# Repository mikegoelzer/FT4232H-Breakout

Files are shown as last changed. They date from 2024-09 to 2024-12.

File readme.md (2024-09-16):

# FT4232H Breakout Board

Breakout board for the FT4232H to support SPI flash programming and JTAG, as well as two UARTs.

<p align="center">
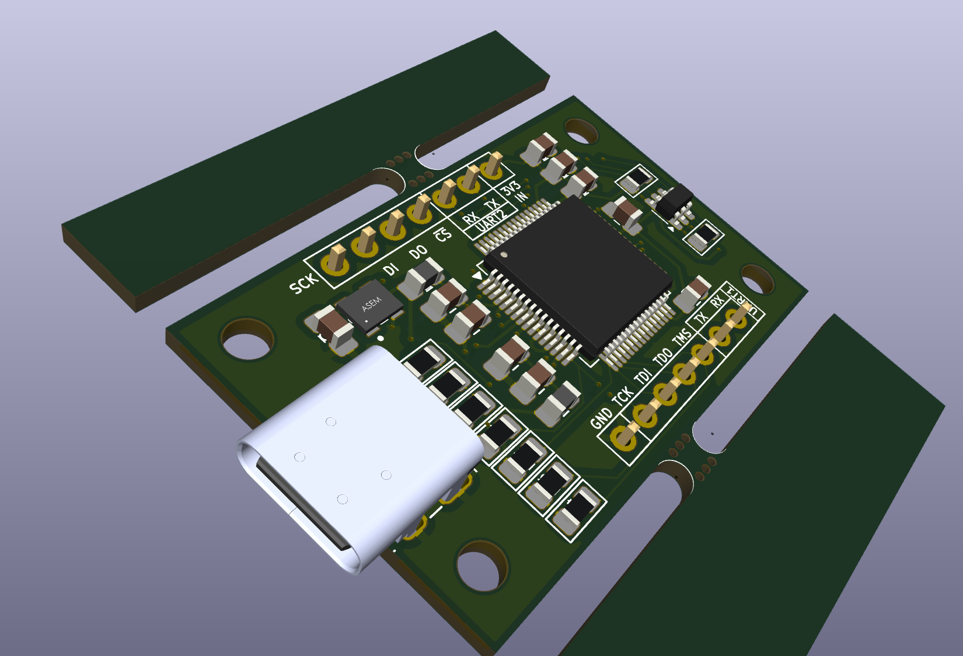
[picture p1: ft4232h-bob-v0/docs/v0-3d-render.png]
FT4232H Breakout Board 3D Render
  
</p>

# Contents

 - [`ft4232h-bob-v0/`](ft4232h-bob-v0/) - Rev 0 of hardware
 - [`mfgr/`](mfgr/) - Files used to initial the EEPROM in a newly built device. See [`mfgr/README.md`](mfgr/README.md)
 - [`ft4232h-bob-v0/docs/`](ft4232h-bob-v0/docs/) - Documentation:
   - [`ft4232h-bob-v0/docs/Improvements.md`](ft4232h-bob-v0/docs/Improvements.md) - Improvements to make to for next revision of board

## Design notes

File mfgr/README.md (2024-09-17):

# FTDI FT4232H Breakout Board EEPROM Programmer

Requires:  [`ftdi-eeprom`](https://github.com/nblock/libftdi/tree/master/ftdi_eeprom) utility in PATH

```
sudo apt install ftdi-eeprom
```

The EEPROM is flashed from `config.txt` file in this directory. Run `man ftdi_eeprom` to see possible config file options.

### Reading

Read the current EEPROM settings:

```
make read
```

### Flashing

Flashing from `config.txt` file's settings:

```
make flash
```

**Notes**

 - You must UNPLUG and REPLUG the FTDI device for `make flash` changes to become visible to the OS.
 - It is not necessary to first erase the EEPROM.
 - When the EEPROM is first initialized on a new board, `make flash` may need to be run **twice** for unknown reasons.

### Erasing

To erase the EEPROM (not in Makefile because not normally required):

```
sudo ftdi_eeprom --device i:0x0403:0x6011 --verbose --erase-eeprom config.txt
```

You will now need to run `make flash` **twice** to write the new settings. The first `make flash` never "takes" for some reason.

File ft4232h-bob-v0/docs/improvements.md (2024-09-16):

# Improvements for FT4232H Breakout Board v1

This is a list of improvements to implement when transitioning from v0 to v1 of the board.

- [ ] `MISO` and `MOSI` are reversed, as are the `DI`/`DO` silkscreens:
  - [ ] Schematic net names: swap MISO and MOSI on pins 27 and 28 so they are like this:
    - [ ] Pin 27:  MOSI
    - [ ] Pin 28:  MISO
    - [ ] Breakout pin 6:  MOSI
    - [ ] Breakout pin 5:  MISO
  - [ ] On PCB, now swap silkscreen DI/DO so they match:
    - [ ] MOSI = DO
    - [ ] MISO = DI
- [ ] JTAG `TDI`/`TDO` are not reversed but naming is **ambiguous**:
  - [ ] Schematic changes:
    - [ ] DO NOT REVERSE ANYTHING
    - [ ] Pin 17: change net name `TDI` -> `DO_TDI`
    - [ ] Pin 18: change net name `TDO` -> `DI_TDO`
    - [ ] Leave breakout pins unchanged (3=`DO_TDI`, 4=`DI_TDO`)
  - [ ] PCB:
    - [ ] If possible, change silkscreen on `3`:  `TDI` -> `TDI/DO`
    - [ ] If possible, change silkscreen on `4`:  `TDO` -> `TDO/DI`
- [ ] [Switch to a better 16P USB-C connector](https://github.com/mikegoelzer/ft4232h-breakout/issues/1)
  - Initial one had through-hole pins that were hard to solder
  - `USB4105-GF-A-120` is the right one for this
    - (without the `-120` is ok too)
- [ ] [Modify stencil apertures following IPC-7525 recommendations](https://github.com/mikegoelzer/ft4232h-breakout/issues/1)
  - Reduce stencil aperture by 10-15% for fine-pitch pads (e.g., LFQP-64 part)
  - Prevents bridging and wicking of solder up the leads during reflow
- [ ] [Round the corners of stencil apertures](https://github.com/mikegoelzer/ft4232h-breakout/issues/1)
  - Improves paste release
  - Prevents bridging during reflow
- [ ] [Increase the number of mousebites on each "assembly tab"](https://github.com/mikegoelzer/ft4232h-breakout/issues/1)
  - Double the current amount
  - Improves mechanical attachment of breakaway assembly tabs to the board
- [ ] [Add non-plated holes on one of the assembly tabs](https://github.com/mikegoelzer/ft4232h-breakout/issues/1)
  - Serves as a thermcouple attachment point
- [ ] [Address USB-C connector height issue during back-side paste application](https://github.com/mikegoelzer/ft4232h-breakout/issues/1)
  - Find standoffs of the exact right height
  - Allows upside-down board to lie flat during back-side paste application
- [ ] [Use stainless steel stencil](https://github.com/mikegoelzer/ft4232h-breakout/issues/1)
  - Improves paste release and stencil durability
  - Provides better edge definition for fine-pitch components
- [ ] [Replace "hand solder" pads with regular sized 0805 pads](https://github.com/mikegoelzer/ft4232h-breakout/issues/1)
  - Reduces board space usage
  - Improves overall component density
- [ ] [Expand UART breakout](https://github.com/mikegoelzer/ft4232h-breakout/issues/1)
  - Break out additional signals beyond TX/RX for both UARTs
  - Include at least DTR and RTS signals
  - Enables programming of ESP32 modules and other devices requiring flow control
  - Consider breaking out CTS and DSR if space allows for full UART functionality
- [ ] [STRETCH GOAL: Redesign JTAG connection](https://github.com/mikegoelzer/ft4232h-breakout/issues/1)
  - Replace 0.1" holes on the sides with a 3x2 JTAG connector on the top of the board to attach JTAG wires

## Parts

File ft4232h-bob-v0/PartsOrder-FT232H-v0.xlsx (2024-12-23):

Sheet: Sheet1
Desc | Parts | Actual Qty | Order Qty | Price | Subtotal | In basket? | Vendor URL | Mfgr | Mfgr PN | Notes | Digikey | Adafruit | Mouser | Sparkfun
FT4232H Breakout Board
# of boards | 3
FT4232H LFQP-64 | U1 | 1 | 3 | 6.35 | $19.05 | ✅ | https://www.digikey.com/en/products/detail/ftdi-future-technology-devices-international-ltd/FT4232HL-REEL/1986055 | FTDI | FT4232HL
USB-C receptacle thru-hole GCT USB4085-GF-A | J3 | 1 | 3 | 1.16 | $3.48 | ✅ | https://www.digikey.com/en/products/detail/gct/usb4085-gf-a/9859662 | GCT | USB4085-GF-A
RES 12K OHM 1% 1/8W 0805 | R1 | 1 | 3 | 0.03 | $0.08 | ✅ | https://www.digikey.com/en/products/detail/yageo/RC0805FR-0712KL/727568 | YAGEO | RC0805FR-0712KL
RES 4.7K OHM 1% 1/8W 0805 | R2 | 1 | 3 | 0.01 | $0.04 | ✅ | https://www.digikey.com/en/products/detail/yageo/rc0805fr-074k7l/727929 | YAGEO | RC0805FR-074K7L
RES 2.2K OHM 1% 1/8W 0805 | R8 | 1 | 3 | 0.01 | $0.04 | ✅ | https://www.digikey.com/en/products/detail/yageo/RC0805FR-072K2L/727676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 | YAGEO | RC0805FR-072K2L
CAP CER 4.7UF 25V X5R 0805 | C1,C2 | 2 | 6 | 0.18 | $1.09 | ✅ | https://www.digikey.com/en/products/detail/yageo/CC0805KKX5R8BB475/5195277 | YAGEO | CC0805KKX5R8BB475 |  | 1
R 10k 0805 1% | R3,R7,R9,R10,R11-14 | 8 | - | - | - | N/A | N/A |  | Stock | Stock
R 1k 0805 1% | R4 | 1 | - | - | - | N/A | N/A |  | Stock | Stock
Ferrite bead 600 ohms @100mhz 0603 0.6A | FB1,FB2 | 2 | 6 | 0.16 | $0.96 | ✅ | https://www.digikey.com/en/products/detail/murata-electronics/BLM21AG601SN1D/584251 | Murata | BLM21AG601SN1D
RES 5.1K OHM 1% 1/8W 0805 | R5,R6 | 2 | 6 | 0.10 | $0.60 | ✅ | https://www.digikey.com/en/products/detail/yageo/rc0805fr-075k1l/727988 | YAGEO | RC0805FR-075K1L
93LC56BT-I/OT IC EEPROM 2KBIT MIC WIRE SOT23-6 | U2 | 1 | 3 | 0.30 | $0.90 | ✅ | https://www.digikey.com/en/products/detail/microchip-technology/93LC56BT-I-OT/572825 | Microchip | 93LC56BT-I/OT
PGB1010603MR TVS diode | N/A | 0 | 0 | 0.64 | $0.00 | N/A - Skip | https://www.digikey.com/en/products/detail/littelfuse-inc/PGB1010603MR/715755 | Littlefuse | PGB1010603MR
CAP CER 0.1UF 50V X7R 0805 | C3-C11,C14,C15 | 11 | - | - | - | N/A | https://www.digikey.com/en/products/detail/yageo/CC0805KRX7R9BB104/302874 | YAGEO | CC0805KRX7R9BB104 | Stock
CAP CER 10UF 25V X5R 0805 | C12,C13 | 2 | 6 | 0.30 | $1.80 | ✅ | https://www.digikey.com/en/products/detail/yageo/CC0805KKX5R8BB106/5195275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 | YAGEO | CC0805KKX5R8BB106
ASEM1 12.000MHZ 3.3V CMOS oscillator | Y1 | 1 | 3 | 1.72 | $5.16 | ✅ | https://www.digikey.com/en/products/detail/abracon-llc/ASEM1-12-000MHZ-LC-T/1873203 | Abracon | ASEM1-12.000MHZ-LC-T

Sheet: old
Desc | Parts | Actual Qty | Order Qty | Price | Subtotal | In basket? | Ordered? | Vendor URL | Notes | Digikey | Adafruit | Mouser | Sparkfun
Carrier Board
# of boards | 2
0.95" SSD1331 96x64 OLED - 7 pin | U4,U5,U6 |  | 2 | 12.99 | $25.98 | ✅ | ✅ | https://www.amazon.com/HiLetgo-Colorful-Display-SSD1331-Resolution/dp/B0711RKXB5
JS5208 5-way joystick | S5 | 1 | 2 | 3.26 | $6.52 | ✅ | ✅ | https://www.mouser.com/ProductDetail/E-Switch/JS5208?qs=f57gQzlyLiqOzqNCAUlPQg%3D%3D |  |  |  | 1
B3FS-1010P tactile switch, normal height, 6x6mm | S1-4 | 4 | 8 | 0.66 | $5.28 | ✅ | ✅ | https://www.mouser.com/ProductDetail/Omron-Electronics/B3FS-1010P?qs=1tDaWCEHQQ4jIfhNdbxDrQ%3D%3D |  |  |  | 1
ULX3S 45F | U1A & U1B | 1 | 1 | 175 | $175.00 | ✅ | ✅ | https://www.mouser.com/ProductDetail/392-CS-ULX3S-02 |  |  |  | 1
Harwin 2.54 female jumper shunt (to disable ESP32) | - | 1 | 2 | 0.34 | $0.68 | ✅ | ✅ | https://www.mouser.com/ProductDetail/Harwin/M7567-05?qs=WS5Jv%252B%252Bx1qXgP9hE0WpBxA%3D%3D |  |  |  | 1
Header - 2x23-pin Male (PTH, 0.1") | (old solution for board stacking) |  | 0 | 1.05 | $0.00 | N/A | N/A | https://www.sparkfun.com/products/12791 |  |  |  |  | 1
Carrier Board: Hex Digits 7-segment
Double Digit 7-segment Display | U7 | 1 | 2 | 3.29 | $6.58 | ✅ | ✅ | https://www.mouser.com/ProductDetail/Kingbright/DC56-11GWA?qs=sXafwHSx%252BU%252BFqc2jozM64A%3D%3D |  |  |  | 1
NL27WZ14 dual inverter in SC-88 package | U8 | 1 | 8 | 0.32 | $2.56 | ✅ | ✅ | https://www.digikey.com/en/products/detail/onsemi/NL27WZ14DFT2G/920165 |  | 1
820 resistors, 1206 3216 metric | R2-R9 | 8 | 16 | 0.1 | $1.60 | ✅ | ✅ | https://www.digikey.com/en/products/detail/yageo/RC1206JR-07820RL/729342 |  | 1
0.1uF ceramic 1206 50V X7R | C1 | 1 | 4 | 0.11 | $0.44 | ✅ | ✅ | https://www.mouser.com/ProductDetail/KEMET/C1206C104K5RAC7867?qs=r%2FVmNO8Tjq5MvP%2FjoJQjcw%3D%3D |  |  |  | 1
10uF ceramic 1206 | C2 | 1 | 4 | 0.3 | $1.20 | ✅ | ✅ | https://www.mouser.com/ProductDetail/KEMET/C1206C106K4PACTU?qs=nz7vn1PXJ%2Feyzlyip0aTxw%3D%3D |  |  |  | 1
Carrier Board: Buttons, LEDs
10k resistor, 1206 3216 metric | R10-R18 | 9 | 18 | 0.1 | $1.80 | ✅ | ✅ | https://www.digikey.com/en/products/detail/yageo/rc1206jr-0710kl/729209 |  | 1
2.2k resistor, 1206 3216 metric | R19,R20,R21,R22 | 4 | 10 | 0.023 | $0.23 | ✅ | ✅ | https://www.mouser.com/ProductDetail/YAGEO/RC1206JR-132K2L?qs=CteSnpDdeuDG995TpbX0Yw%3D%3D |  |  |  | 1
Blue-Yellow LED | LED1 | 1 | 2 | 0.34 | $0.68 | ✅ | ✅ | https://www.mouser.com/ProductDetail/Wurth-Elektronik/150141YB73100?qs=LlUlMxKIyB0w3o6OoXw%252BvA%3D%3D |  |  |  | 1
Red-Green LED | LED2 | 1 | 2 | 0.34 | $0.68 | ✅ | ✅ | https://www.mouser.com/ProductDetail/Wurth-Elektronik/150141YB73100?qs=LlUlMxKIyB0w3o6OoXw%252BvA%3D%3D |  |  |  | 1
Carrier Board: Connectors
PMOD pins, dual row, breakable (2x40) | J2, J4 maybe; useful to have around | 1 | 2 | 1.53 | $3.06 | ✅ | ✅ | https://www.digikey.com/en/products/detail/w%C3%BCrth-elektronik/61304011121/4846884 |  | 1
Right angle female conn for SPI slaves | J2 | 1 | 2 | 1.11 | $2.22 | ✅ | ✅ | https://www.digikey.com/en/products/detail/w%C3%BCrth-elektronik/613010243121/2508634 |  | 1
Right angle female conn for extra GPIOs | J5 | 0 | 0 | 0.98 | $0.00 | ✅ | ✅ | https://www.digikey.com/en/products/detail/w%C3%BCrth-elektronik/613012243121/16608604 |  | 1
?????? - no solution yet | J4
Carrier Board: Connectors
Socket for OLED on ULX3S: SSW-108-03-T-S | Stacking-B | 1 | 1 | 1.15 | $1.15 | ✅ | ✅ | https://www.mouser.com/ProductDetail/Samtec/SSW-108-03-T-S?qs=rU5fayqh%252BE3c3qziXVp5Bg%3D%3D |  |  |  | 1
Backup in case SSW-108-03-T-S is too tall (this is SSW-108-02-T-S; different body style with shorter female top) | Stacking-B - Alt | 1 | 1 | 1.14 | $1.14 | ✅ | ✅ | https://www.digikey.com/en/products/detail/samtec-inc/SSW-108-02-T-S/1112792 |  | 1
WIFI_EN pins: ordinary 6mm/3mm male/male breakaways | Stacking-C | 0 | 0 |  | $0.00 | N/A | N/A | Already have some
ULX3S side pins (bpth sides): male/male 6/3mm (Ada #2822) | Stacking-A | 2 | 4 | 0.95 | $3.80 | ✅ | ✅ | https://www.adafruit.com/product/2822 |  |  | 1
Backup for Ada #2822: Breakaway male-male 6/3mm headers (Ada #392) | Stacking-A - Alt | 1 | 1 | 4.95 | $4.95 | ✅ | ✅ | https://www.adafruit.com/product/392 |  |  | 1
ULX3S JTAG pins: SSW-103-03-T-D |  | 1 | 2 | 1.1 | $2.20 | ✅ | ✅ | https://www.mouser.com/ProductDetail/Samtec/SSW-103-03-T-D?qs=rU5fayqh%252BE1NxrktfKveRw%3D%3D |  |  |  | 1
Wurth 61300621121: 2x3 male-male 6/3mm | Stacking-D | 1 | 2 | 0.57 | $1.14 | ✅ | ✅ | https://www.digikey.com/en/products/detail/w%C3%BCrth-elektronik/61300621121/4846835 |  | 1
Wurth 61304021821: female-male 6/3mm | Stacking-E | 2 | 4 | 1.92 | $7.68 | ✅ | ✅ | https://www.digikey.com/en/products/detail/w%C3%BCrth-elektronik/61304021821/16608657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 |  | 1
Wurth 6130-08-2-1821: female-male 6/3mm 2x3 config | Stacking-G | 1 | 2 | 0.41 | $0.82 | ✅ | ✅ | https://www.digikey.com/en/products/detail/w%C3%BCrth-elektronik/61300621821/16608633 |  | 1
Same Wurth 6130 ' 1821 line | Stacking-F, Stacking-H | 3 | 6 | 0.42 | $2.52 | ✅ | ✅ | https://www.digikey.com/en/products/detail/w%C3%BCrth-elektronik/61300811821/17737805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 |  | 1
Same Wurth 6130 ' 1821 line | Stacking-I | 2 | 4 | 0.44 | $1.76 | ✅ | ✅ | https://www.digikey.com/en/products/detail/w%C3%BCrth-elektronik/61300411821/16608539 |  | 1
Same Wurth 6130 ' 1821 line, but this is 4x16 pins; you'll need to break it down to 11 | Stacking-Bottom-FTDIs | 4 | 8 | 0.63 | $5.04 | ✅ | ✅ | https://www.digikey.com/en/products/detail/w%C3%BCrth-elektronik/61301611821/6137797 |  | 1
SMT - ULX3S edges connector: 2x20 | Stacking-A - SMT | 2 | 3 | 6.74 | $20.22 | ✅ | ✅ | https://www.mouser.com/ProductDetail/Wurth-Elektronik/61004021821?qs=ulEaXIWI0c8dfRNq4HxjEg%3D%3D
Carrier Board: Power
DC barrel jack CUI-PJ102AH | J6 | 1 | 4 | 0.95 | $3.80 | ✅ | ✅ | https://www.adafruit.com/product/373
FTDI Boards (QSPI and JTAG)
# of boards | 2
FTDI breakout boards x 2 |  | 0 | 0 | 14.95 | $0.00 | N/A | N/A | https://www.adafruit.com/product/2264 |  |  | 1
2.8" TFT LCD with Touchscreen Breakout Board | For testing | 1 | 1 | 29.95 | $29.95 | ✅ | ✅ | https://www.adafruit.com/product/2090 |  |  | 1
10k resistor, 1206 3216 metric | R1 | 1 | 2 | 0.1 | $0.20 | ✅ | ✅ | https://www.digikey.com/en/products/detail/yageo/rc1206jr-0710kl/729209 |  | 1

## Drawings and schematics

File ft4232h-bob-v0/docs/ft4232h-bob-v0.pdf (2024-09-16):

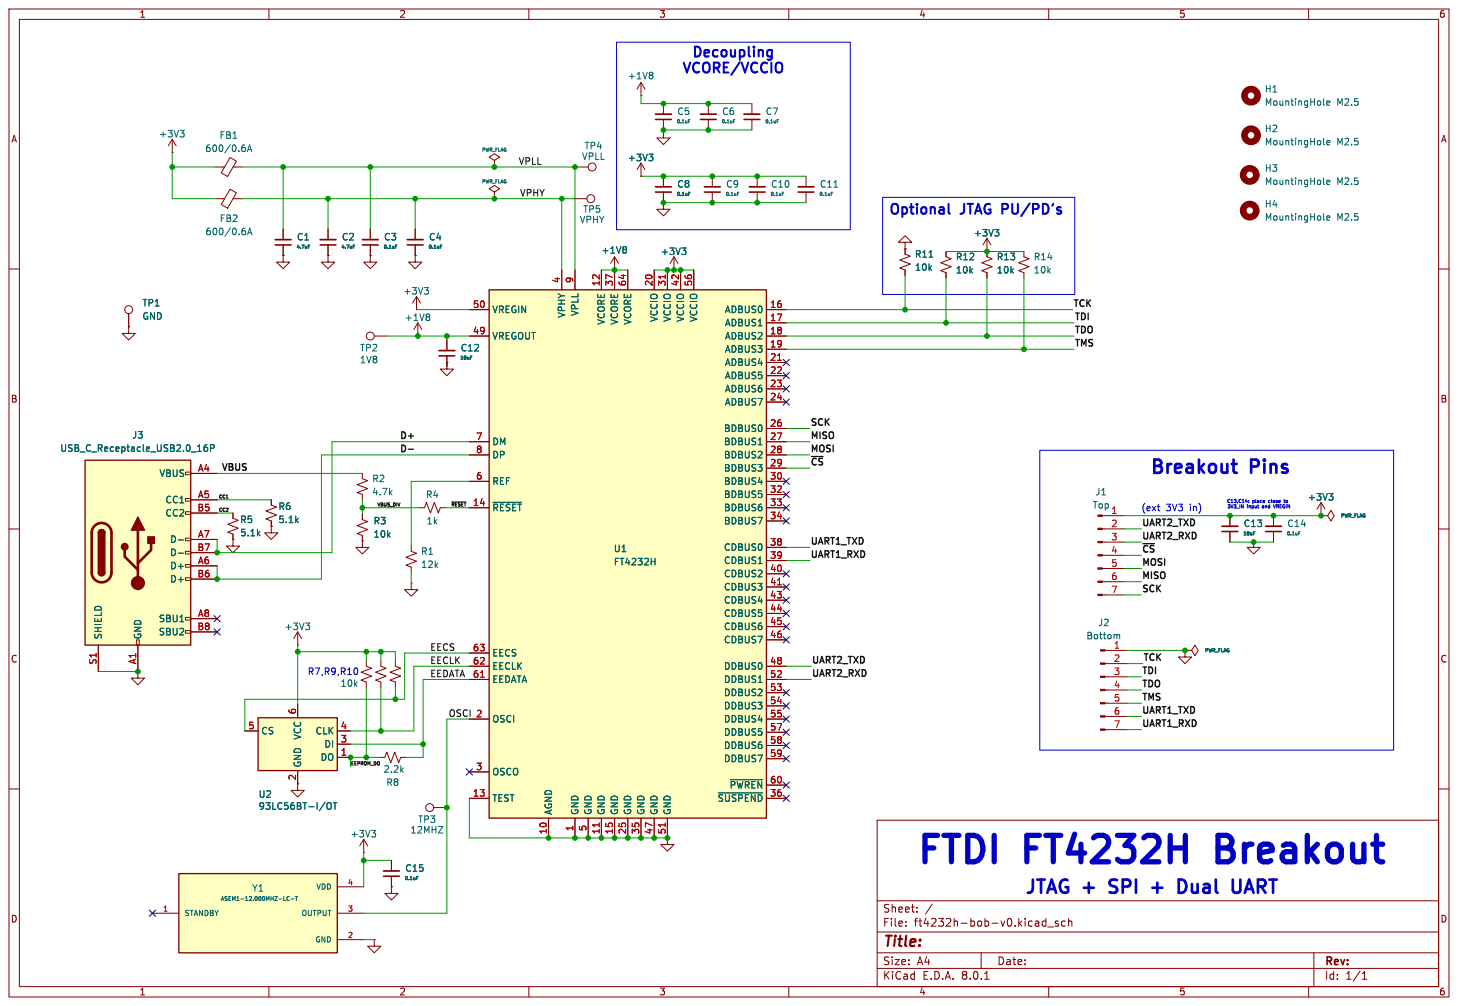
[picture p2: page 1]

3V3_IN input and VREGIN Decoupling
VCORE/VCCIO

Optional JTAG PU/PD's

1 AGND 10 GND 11 VCORE 12 TEST 13 ~{RESET} 14 GND 15 ADBUS0 16 ADBUS1 17 ADBUS2 18 ADBUS3 19 OSCI 2 VCCIO 20 ADBUS4 21 ADBUS5 22 ADBUS6 23 ADBUS7 24 GND 25 BDBUS0 26 BDBUS1 27 BDBUS2 28 BDBUS3 29 OSCO 3 BDBUS4 30 VCCIO 31 BDBUS5 32 BDBUS6 33 BDBUS7 34 GND 35

4 CDBUS2 40 CDBUS3 41 VCCIO 42 CDBUS4 43 CDBUS5 44 CDBUS6 45 CDBUS7 46 GND 47 DDBUS0 48 VREGOUT 49 GND

5 VREGIN 50 GND 51 DDBUS1 52 DDBUS2 53 DDBUS3 54 DDBUS4 55 VCCIO 56 DDBUS5 57 DDBUS6 58 DDBUS7 59 REF 6 ~{PWREN}60 EEDATA 61 EECLK 62 EECS 63 VCORE 64 DM 7 DP 8 VPLL

2 DI 3 CLK 4 CS 5 VCC

Id: 1/1 Title: File: ft4232h-bob-v0.kicad_sch Sheet: /

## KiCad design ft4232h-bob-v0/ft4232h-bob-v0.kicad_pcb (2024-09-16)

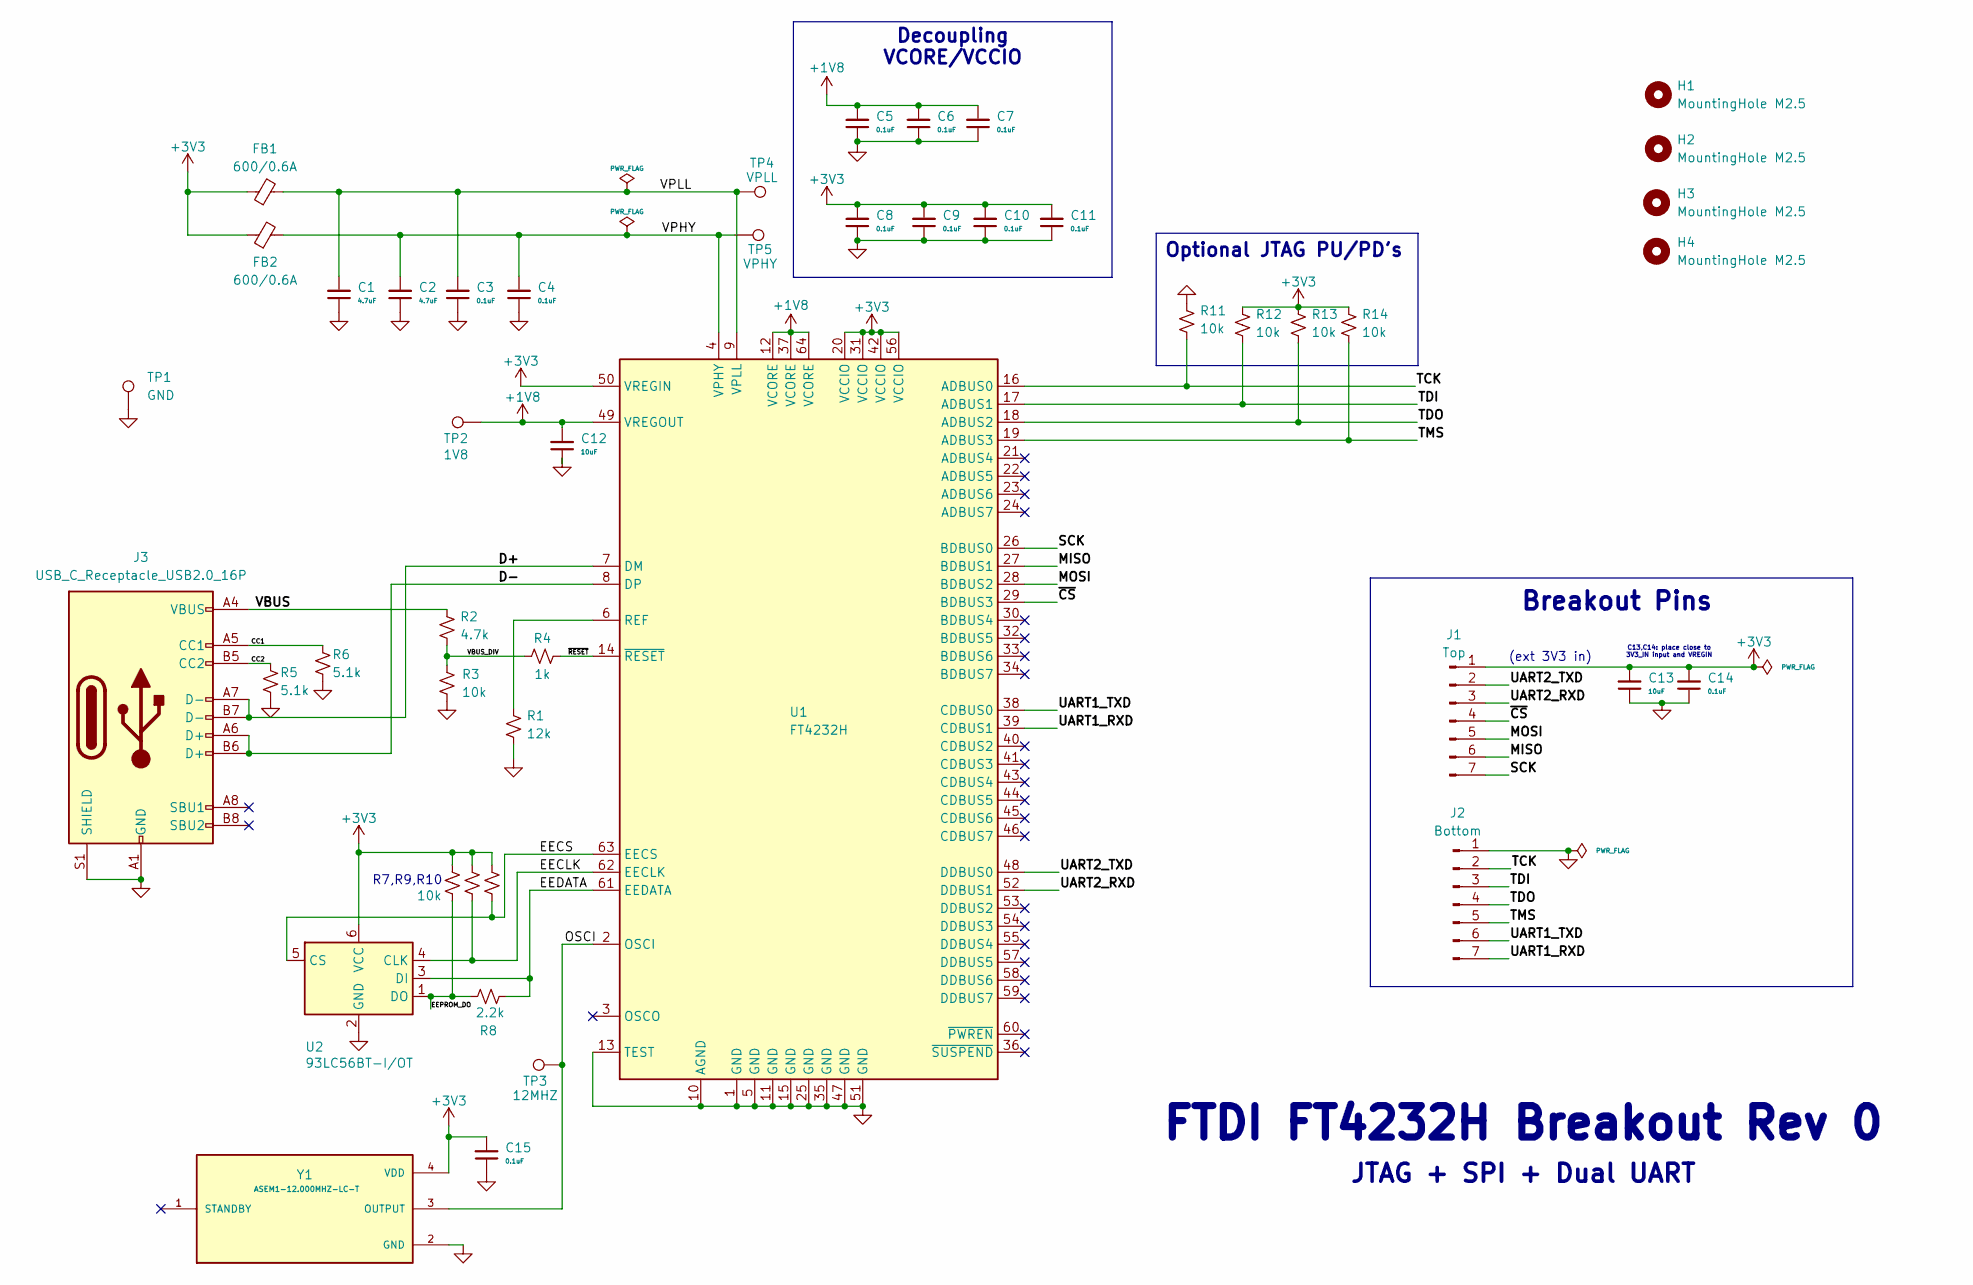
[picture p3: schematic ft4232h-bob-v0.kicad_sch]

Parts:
C1, C2: 4.7uF; C_0805_2012Metric_Pad1.18x1.45mm_HandSolder
C3, C4, C5, C6, C7, C8, C9, C10, C11, C14, C15: 0.1uF; C_0805_2012Metric_Pad1.18x1.45mm_HandSolder
C12, C13: 10uF; C_0805_2012Metric_Pad1.18x1.45mm_HandSolder
FB1, FB2: 600/0.6A; L_0805_2012Metric_Pad1.15x1.40mm_HandSolder
H1, H2, H3, H4: MountingHole M2.5; MountingHole_2.7mm_M2.5_ISO7380
J1: Top; PinHeader_1x07_P2.54mm_Vertical-Circular-Pads
J2: Bottom; PinHeader_1x07_P2.54mm_Vertical-Circular-Pads
J3: USB_C_Receptacle_USB2.0_16P; USB_C_Receptacle_GCT_USB4085
R1: 12k; R_0805_2012Metric_Pad1.15x1.40mm_HandSolder
R2: 4.7k; R_0805_2012Metric_Pad1.15x1.40mm_HandSolder
R3, R7, R9, R10, R11, R12, R13, R14: 10k; R_0805_2012Metric_Pad1.15x1.40mm_HandSolder
R4: 1k; R_0805_2012Metric_Pad1.15x1.40mm_HandSolder
R5, R6: 5.1k; R_0805_2012Metric_Pad1.15x1.40mm_HandSolder
R8: 2.2k; R_0805_2012Metric_Pad1.15x1.40mm_HandSolder
TP1: GND; TestPoint_Pad_2.0x2.0mm
TP2: 1V8; TestPoint_Pad_2.0x2.0mm
TP3: 12MHZ; TestPoint_Pad_2.0x2.0mm
TP4: VPLL; TestPoint_Pad_2.0x2.0mm
TP5: VPHY; TestPoint_Pad_2.0x2.0mm
U1: FT4232H; LQFP-64_10x10mm_P0.5mm
U2: 93LC56BT-I/OT; SOT-23-6; MPN 93LC56BT-I/OT
Y1: ASEM1-12.000MHZ-LC-T; XTAL_ASEM1-12.000MHZ-LC-T; PARTREV 1.4.2021

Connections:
+1V8: C5.2, C6.2, C7.2, C12.2, TP2.1, U1.12 (VCORE), U1.37 (VCORE), U1.49 (VREGOUT), U1.64 (VCORE)
+3V3: C8.2, C9.2, C10.2, C11.2, C13.2, C14.2, C15.2, FB1.1, FB2.1, J1.1, R7.1, R9.1, R10.1, R12.1, R13.1, R14.1, U1.20 (VCCIO), U1.31 (VCCIO), U1.42 (VCCIO), U1.50 (VREGIN), U1.56 (VCCIO), U2.6 (VCC), Y1.4 (VDD)
/CC1: J3.A5 (CC1), R6.1
/CC2: J3.B5 (CC2), R5.1
/D+: J3.A7 (D-), J3.B7 (D-), U1.7 (DM)
/D-: J3.A6 (D+), J3.B6 (D+), U1.8 (DP)
/EECLK: R9.2, U1.62 (EECLK), U2.4 (CLK)
/EECS: R10.2, U1.63 (EECS), U2.5 (CS)
/EEDATA: R8.2, U1.61 (EEDATA), U2.3 (DI)
/EEPROM_DO: R7.2, R8.1, U2.1 (DO)
/MISO: J1.6, U1.27 (BDBUS1)
/MOSI: J1.5, U1.28 (BDBUS2)
/OSCI: TP3.1, U1.2 (OSCI), Y1.3 (OUTPUT)
/SCK: J1.7, U1.26 (BDBUS0)
/TCK: J2.2, R11.2, U1.16 (ADBUS0)
/TDI: J2.3, R12.2, U1.17 (ADBUS1)
/TDO: J2.4, R13.2, U1.18 (ADBUS2)
/TMS: J2.5, R14.2, U1.19 (ADBUS3)
/UART1_RXD: J2.7, U1.39 (CDBUS1)
/UART1_TXD: J2.6, U1.38 (CDBUS0)
/UART2_RXD: J1.3, U1.52 (DDBUS1)
/UART2_TXD: J1.2, U1.48 (DDBUS0)
/VBUS: J3.A4 (VBUS), J3.A9 (VBUS), J3.B4 (VBUS), J3.B9 (VBUS), R2.1
/VBUS_DIV: R2.2, R3.1, R4.1
/VPHY: C2.2, C4.2, FB2.2, TP5.1, U1.4 (VPHY)
/VPLL: C1.2, C3.2, FB1.2, TP4.1, U1.9 (VPLL)
/~CS: J1.4, U1.29 (BDBUS3)
/~RESET: R4.2, U1.14 (~RESET)
GND: C1.1, C2.1, C3.1, C4.1, C5.1, C6.1, C7.1, C8.1, C9.1, C10.1, C11.1, C12.1, C13.1, C14.1, C15.1, J2.1, J3.A1 (GND), J3.A12 (GND), J3.B1 (GND), J3.B12 (GND), J3.S1 (SHIELD), R1.2, R3.2, R5.2, R6.2, R11.1, TP1.1, U1.1 (GND), U1.5 (GND), U1.10 (AGND), U1.11 (GND), U1.13 (TEST), U1.15 (GND), U1.25 (GND), U1.35 (GND), U1.47 (GND), U1.51 (GND), U2.2 (GND), Y1.2 (GND)
unnamed: R1.1, U1.6 (REF)

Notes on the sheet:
Optional JTAG PU/PD's
Breakout Pins
FTDI FT4232H Breakout Rev 0
Decoupling VCORE/VCCIO
JTAG + SPI + Dual UART
(ext 3V3 in)
C13,C14: place close to 3V3_IN input and VREGIN
R7,R9,R10

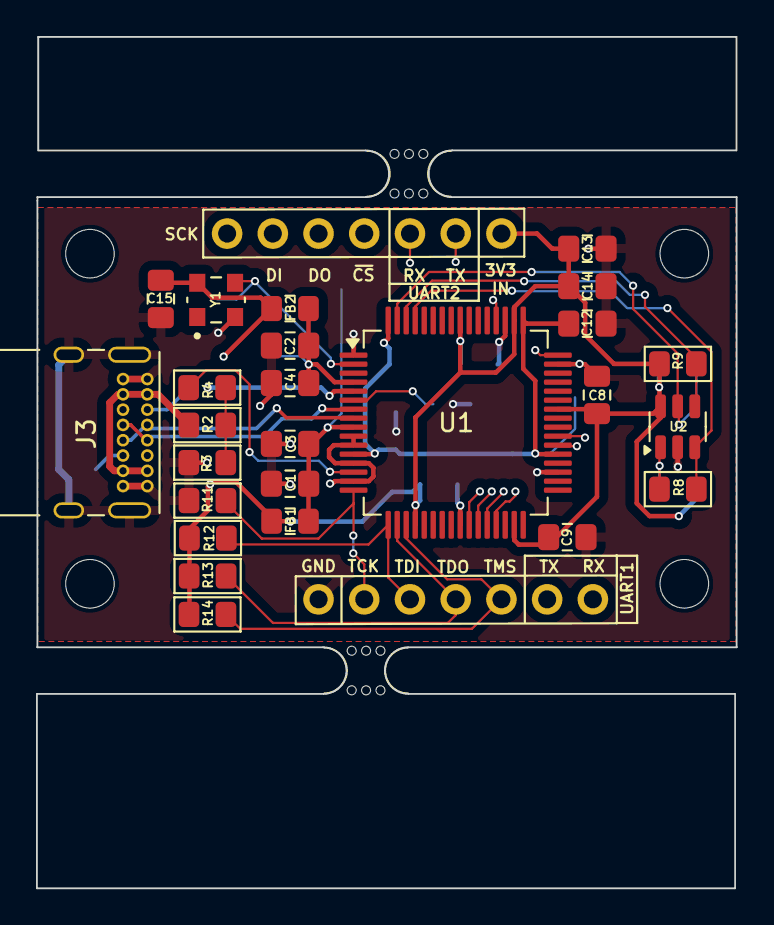
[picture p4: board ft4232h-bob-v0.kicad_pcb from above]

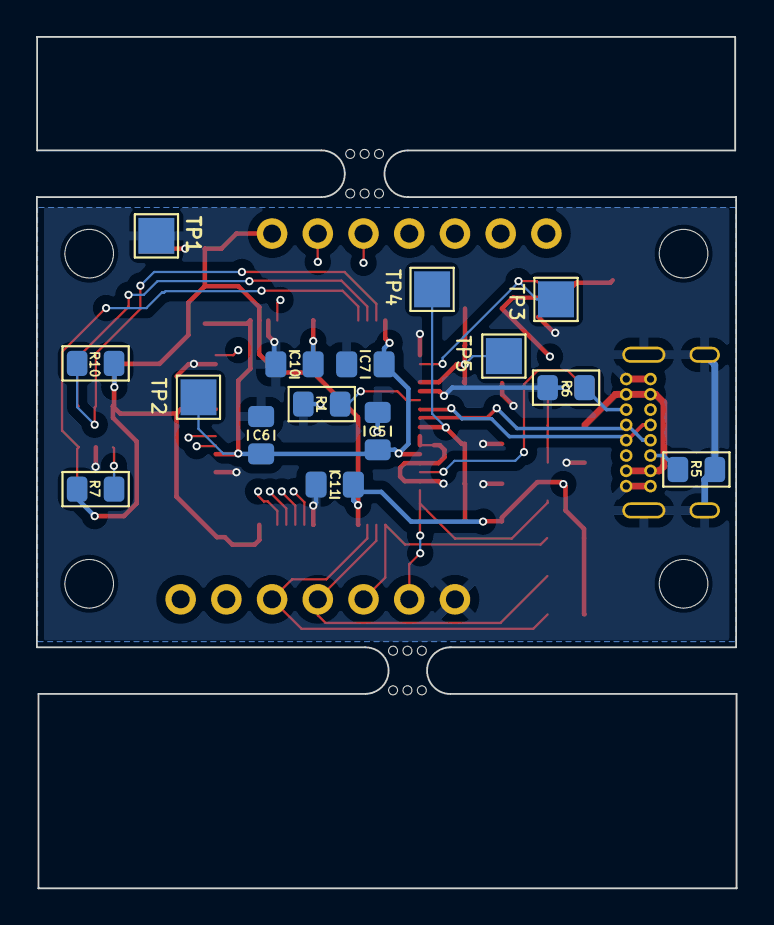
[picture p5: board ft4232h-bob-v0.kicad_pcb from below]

Board: 4 copper layers, 38.9 x 47.3 mm, 48 parts (15 on the bottom side), 30 nets.

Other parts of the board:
mouse-bite-2.54mm-slot, mouse-bite-2.54mm-slot#2: VAL**; mouse-bite-2.54mm-slot

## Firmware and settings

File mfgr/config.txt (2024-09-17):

# Reference:  
#  - See `man ftdi_eeprom` for config file hints.
#  - See `zcat /usr/share/doc/ftdi-eeprom/example.conf.gz` for example config file

############
# Filename #
############
#filename=eeprom.new               # Filename of the EE file to be generated. Leave empty to skip file writing

# FTDI defaults
vendor_id=0x0403
product_id=0x6011

# Rev 0 is self-powered
self_powered=true
max_power=0                        # in multiples of 2mA; use 0 if self_powered = true.

# Strings
manufacturer="MWG"
product="MWG's FT4232H Rev0"       # this seems to have a length limit of ~20 chars
serial="091624"
use_serial=true

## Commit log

2024-09-16 initial commit: v0 hardware + eepromm initialization files
    [PartsOrder-FT232H-v0.xlsx, config.txt, ft4232h-bob-v0.kicad_pcb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]
2024-09-17 fix empty serial number in ftdiflash -l
    [config.txt]
2024-12-23 minor edit to spreadsheet
    [PartsOrder-FT232H-v0.xlsx]
2024-12-30 added schematic note about MISO/MOSI swap needed (see improvements.md)
    [ft4232h-bob-v0.kicad_sch]
